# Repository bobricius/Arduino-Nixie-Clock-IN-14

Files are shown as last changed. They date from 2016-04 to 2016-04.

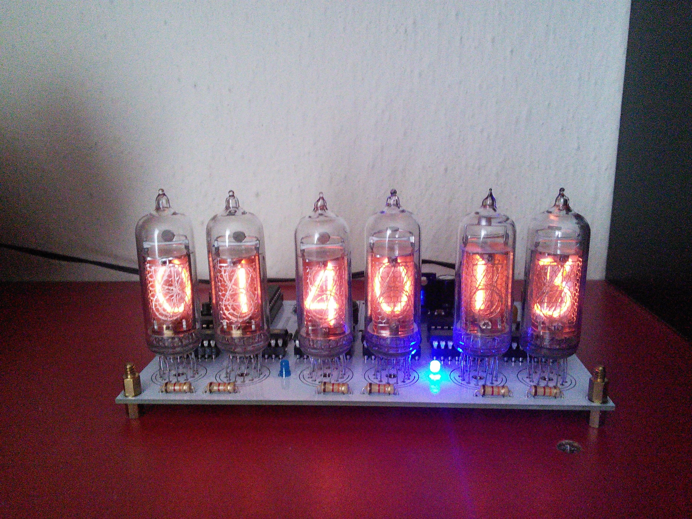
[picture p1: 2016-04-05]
Images/a2.jpg

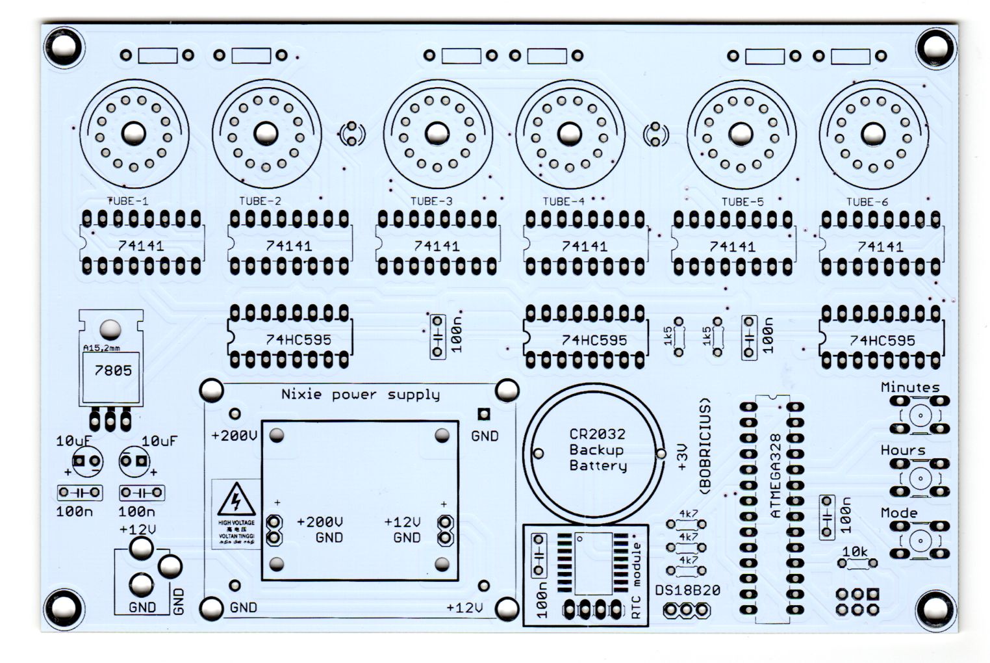
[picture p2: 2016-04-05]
Images/bare_t.jpg

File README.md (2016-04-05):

Features:

- 24h mode
- easy assembly
- arduino compatible firmware ATMEGA328 or another runing on internal RC oscillator (no crystal needed )
- ultra high precise time with RTC DS3231 onboard or RTC module
- CR2032 battery backup
- separated HV power supply (not included, you can connect any HV module) 
 etc. specially THIS ONE from ebay fit prefect.
- beautiful white single board 
- readable clean design
- cathode poisoning prevention
- 3mm holes under nixies for optional back-light
- optional DS18B20 sensor
- dimensions 15cm x 10cm

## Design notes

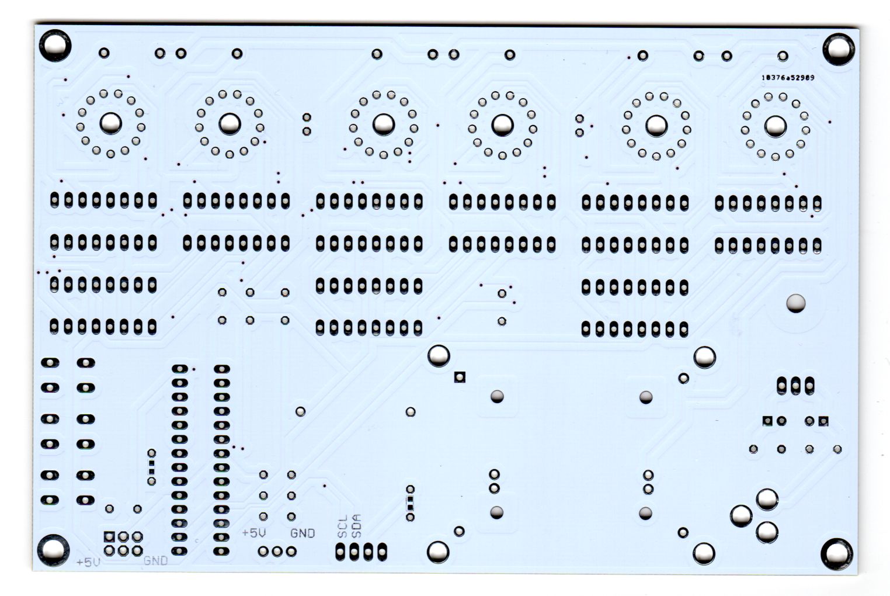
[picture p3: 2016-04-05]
Images/bare_b.jpg

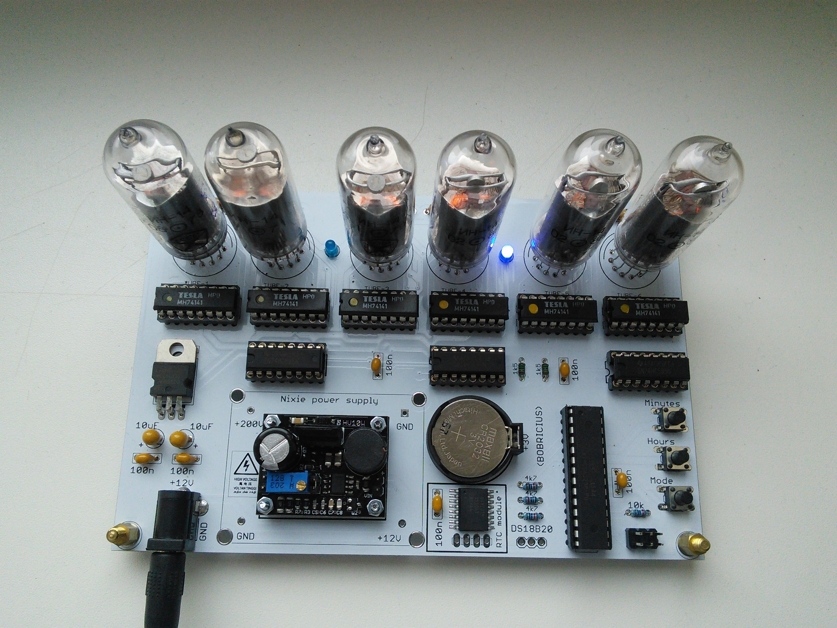
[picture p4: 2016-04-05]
Images/a1.jpg

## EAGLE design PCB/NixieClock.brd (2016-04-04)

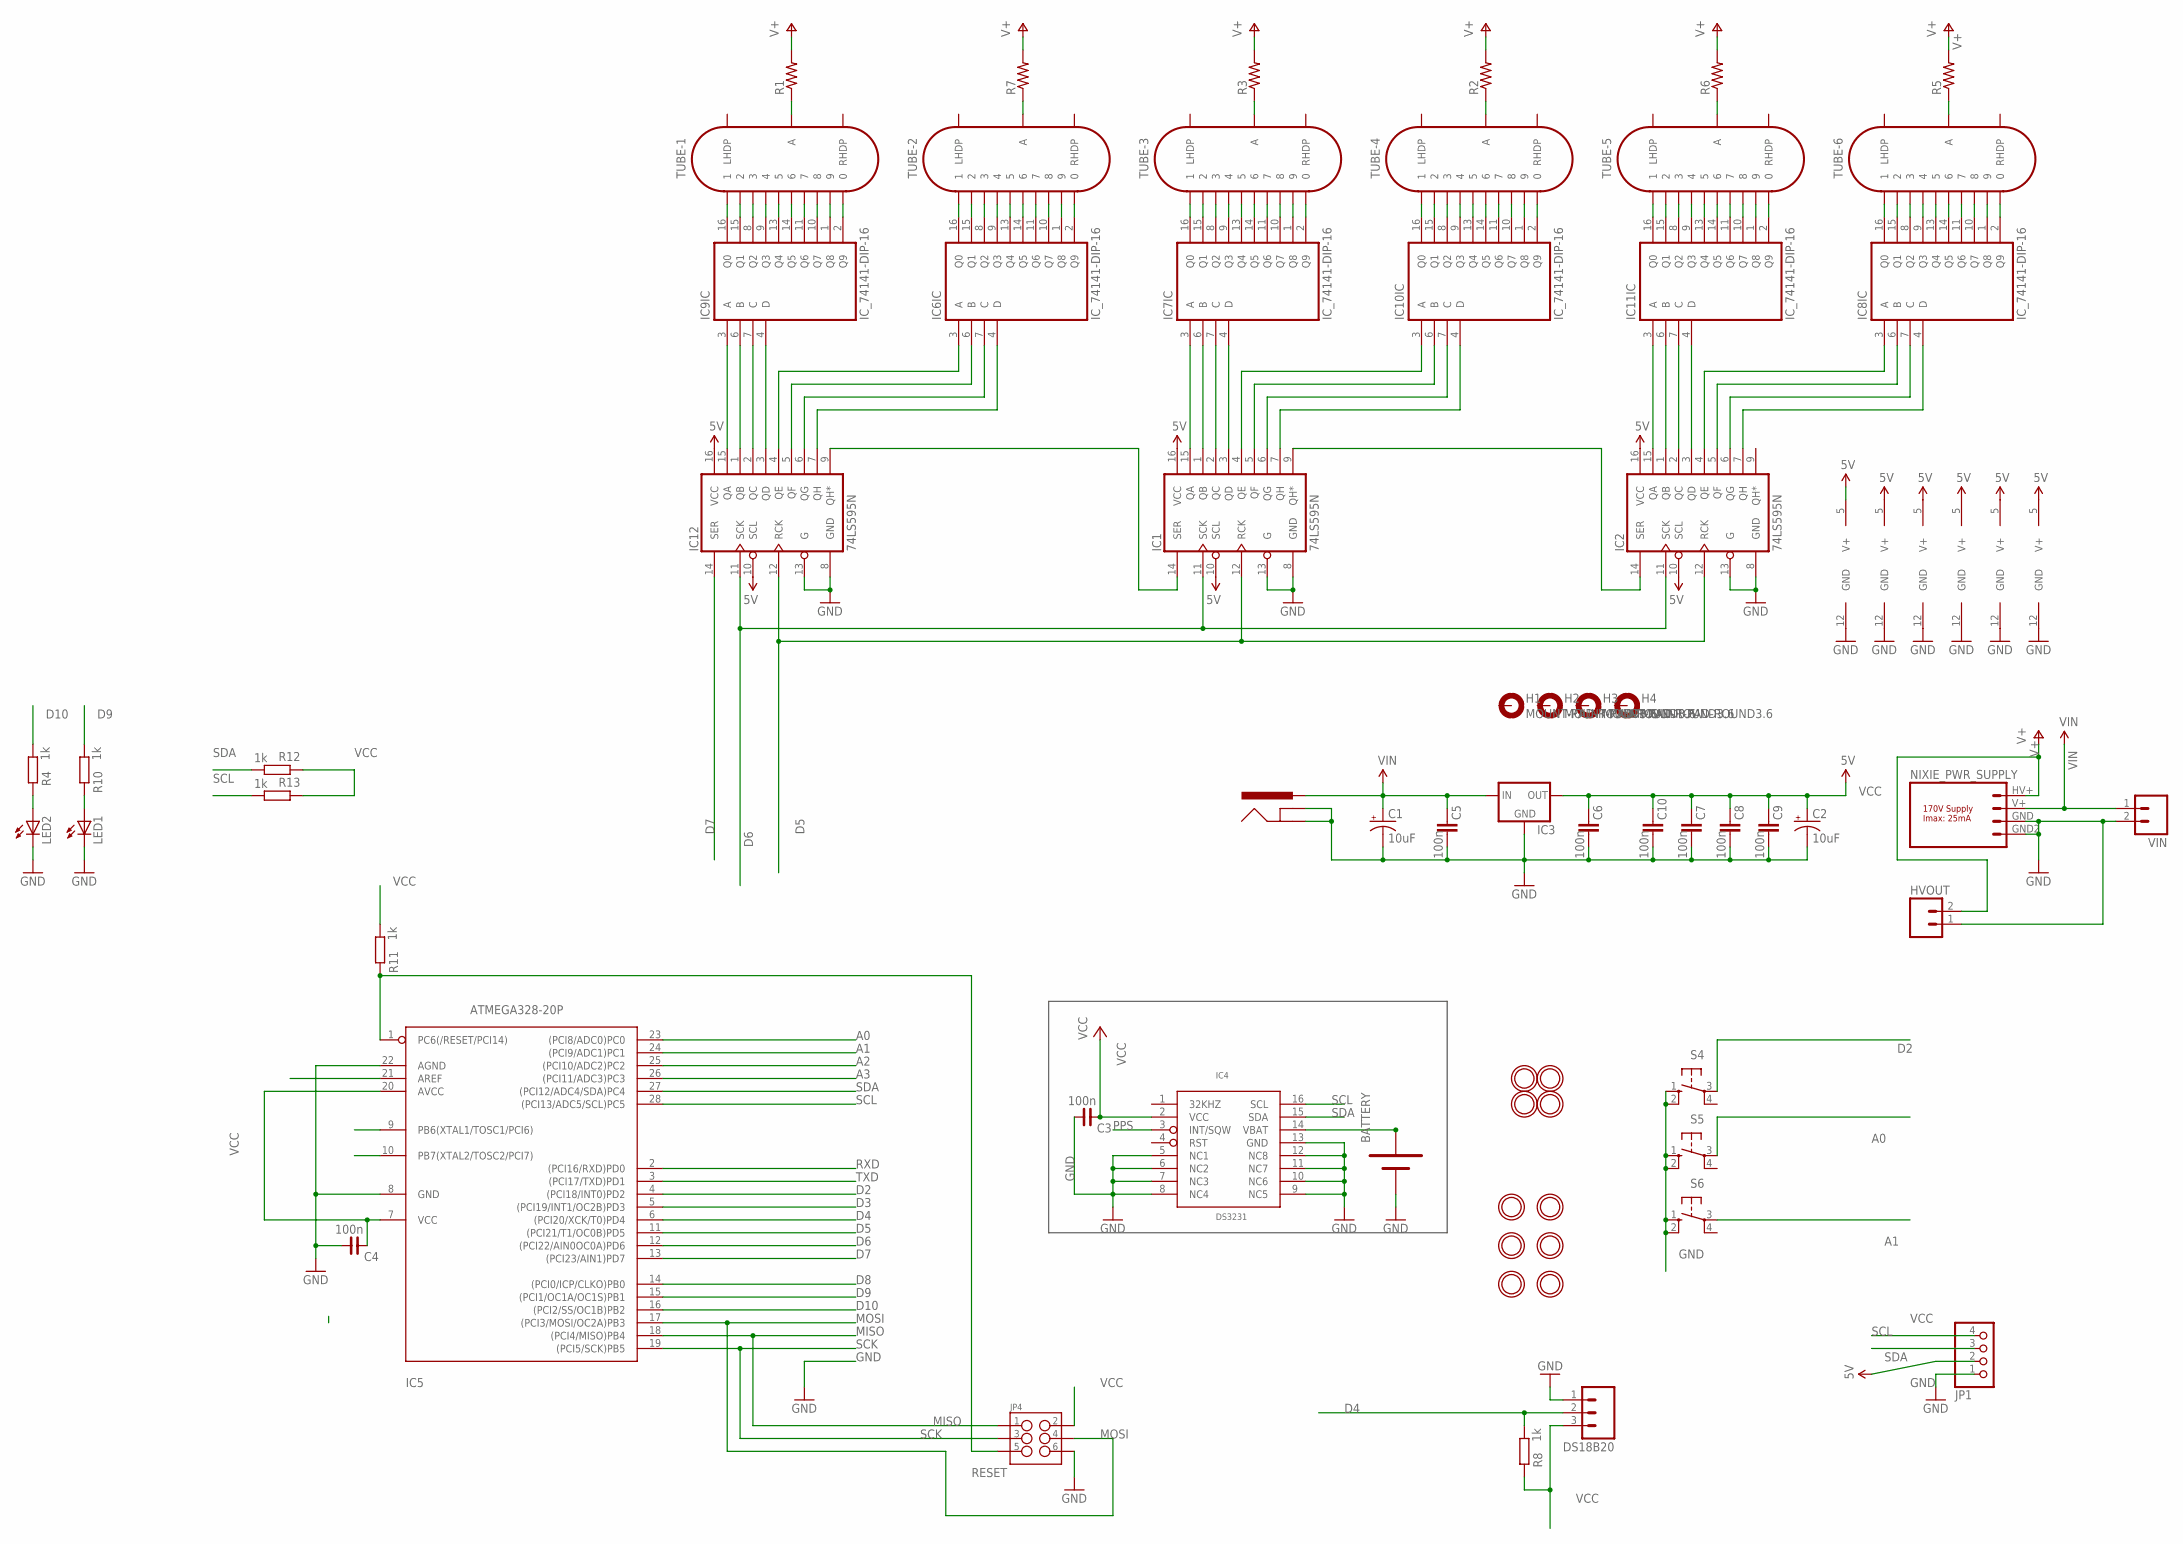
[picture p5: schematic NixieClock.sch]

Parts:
BATTERY: BATTERY-1XAA20MM; BATTCOM_20MM_PTH
C1, C2: 10uF; CPOL-RADIAL-10UF-25V
C3, C4: 100n; C0603
C5, C6, C7, C8, C9, C10: 100n; C050-025X075
DS18B20: DS18B20DS18B20; DS18B20
H1, H2, H3, H4: MOUNT-PAD-ROUND3.6; 3,6-PAD
HVOUT: M02PTH; 1X02
IC1, IC2, IC12: 74LS595N; DIL16
IC3: V_REG_78XXSIDE; 78XXL
IC4: DS3231; SO16W
IC5: ATMEGA328-20P; DIL28-3
IC6, IC7, IC8, IC9, IC10, IC11: IC_74141-DIP-16; DIL16
J1: POWER_JACKPTH; POWER_JACK_PTH
JP1: PINHD-1X4; 1X04
JP4: M03X2NO_SILK; 2X3-NS
LED1, LED2: LED3MM
NIXIE_PWR_SUPPLY: NIXIE_PWR_SUPPLYPTH; NIXIE_PWR_SUPPLY
R1, R2, R3, R5, R6, R7: RESISTORPTH-1/4W; AXIAL-0.4
R4, R8, R10, R11, R12, R13: 1k; 0204/5
S4, S5, S6: 10-XX; B3F-10XX
TUBE-1, TUBE-2, TUBE-3, TUBE-4, TUBE-5, TUBE-6: IN-14
U$10, U$11, U$16, U$17, U$18, U$19, U$21, U$22, U$23, U$24: MOUNTINGHOLE3.0THIN; MOUNTINGHOLE_3.0_PLATEDTHIN
VIN: M02PTH; 1X02

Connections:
A0: IC5.23 ((PCI8/ADC0)PC0), S5.3
A1: IC5.24 ((PCI9/ADC1)PC1), S6.3
A2: IC5.25 ((PCI10/ADC2)PC2)
A3: IC5.26 ((PCI11/ADC3)PC3)
AREF_RAW: IC5.21 (AREF)
D2: IC5.4 ((PCI18/INT0)PD2), S4.3
D3: IC5.5 ((PCI19/INT1/OC2B)PD3)
D4: DS18B20.2 (DS), IC5.6 ((PCI20/XCK/T0)PD4), R8.1
D5: IC1.12 (RCK), IC2.12 (RCK), IC5.11 ((PCI21/T1/OC0B)PD5), IC12.12 (RCK)
D6: IC1.11 (SCK), IC2.11 (SCK), IC5.12 ((PCI22/AIN0OC0A)PD6), IC12.11 (SCK)
D7: IC5.13 ((PCI23/AIN1)PD7), IC12.14 (SER)
D8: IC5.14 ((PCI0/ICP/CLKO)PB0)
D9: IC5.15 ((PCI1/OC1A/OC1S)PB1), R10.1
D10: IC5.16 ((PCI2/SS/OC1B)PB2), R4.1
GND: BATTERY.-, C1.2 (-), C2.2 (-), C3.1, C4.1, C5.2, C6.2, C7.2, C8.2, C9.2, C10.2, DS18B20.1 (GND), HVOUT.1, IC1.8 (GND), IC1.13 (G), IC2.8 (GND), IC2.13 (G), IC3.GND, IC4.5 (NC1), IC4.6 (NC2), IC4.7 (NC3), IC4.8 (NC4), IC4.9 (NC5), IC4.10 (NC6), IC4.11 (NC7), IC4.12 (NC8), IC4.13 (GND), IC5.8 (GND), IC5.22 (AGND), IC6.12 (GND), IC7.12 (GND), IC8.12 (GND), IC9.12 (GND), IC10.12 (GND), IC11.12 (GND), IC12.8 (GND), IC12.13 (G), J1.GND, J1.GNDBREAK, JP1.1, JP4.6, LED1.K (C), LED2.K (C), NIXIE_PWR_SUPPLY.GND (4), NIXIE_PWR_SUPPLY.GND2 (1), S4.1 (S), S4.2 (S1), S5.1 (S), S5.2 (S1), S6.1 (S), S6.2 (S1), VIN.2
MISO: IC5.18 ((PCI4/MISO)PB4), JP4.1
MOSI: IC5.17 ((PCI3/MOSI/OC2A)PB3), JP4.4
unnamed: R1.P$1 (1), TUBE-1.A
unnamed: R7.P$1 (1), TUBE-2.A
unnamed: R3.P$1 (1), TUBE-3.A
unnamed: R2.P$1 (1), TUBE-4.A
unnamed: R6.P$1 (1), TUBE-5.A
unnamed: R5.P$1 (1), TUBE-6.A
unnamed: IC9.16 (Q0), TUBE-1.1
unnamed: IC9.15 (Q1), TUBE-1.2
unnamed: IC9.8 (Q2), TUBE-1.3
unnamed: IC9.9 (Q3), TUBE-1.4
unnamed: IC9.13 (Q4), TUBE-1.5
unnamed: IC9.14 (Q5), TUBE-1.6
unnamed: IC9.11 (Q6), TUBE-1.7
unnamed: IC9.10 (Q7), TUBE-1.8
unnamed: IC9.1 (Q8), TUBE-1.9
unnamed: IC9.2 (Q9), TUBE-1.0
unnamed: IC6.16 (Q0), TUBE-2.1
unnamed: IC6.15 (Q1), TUBE-2.2
unnamed: IC6.8 (Q2), TUBE-2.3
unnamed: IC6.9 (Q3), TUBE-2.4
unnamed: IC6.13 (Q4), TUBE-2.5
unnamed: IC6.14 (Q5), TUBE-2.6
unnamed: IC6.11 (Q6), TUBE-2.7
unnamed: IC6.10 (Q7), TUBE-2.8
unnamed: IC6.1 (Q8), TUBE-2.9
unnamed: IC6.2 (Q9), TUBE-2.0
unnamed: IC7.16 (Q0), TUBE-3.1
unnamed: IC7.15 (Q1), TUBE-3.2
unnamed: IC7.8 (Q2), TUBE-3.3
unnamed: IC7.9 (Q3), TUBE-3.4
unnamed: IC7.13 (Q4), TUBE-3.5
unnamed: IC7.14 (Q5), TUBE-3.6
unnamed: IC7.11 (Q6), TUBE-3.7
unnamed: IC7.10 (Q7), TUBE-3.8
unnamed: IC7.1 (Q8), TUBE-3.9
unnamed: IC7.2 (Q9), TUBE-3.0
unnamed: IC10.16 (Q0), TUBE-4.1
unnamed: IC10.15 (Q1), TUBE-4.2
unnamed: IC10.8 (Q2), TUBE-4.3
unnamed: IC10.9 (Q3), TUBE-4.4
unnamed: IC10.13 (Q4), TUBE-4.5
unnamed: IC10.14 (Q5), TUBE-4.6
unnamed: IC10.11 (Q6), TUBE-4.7
unnamed: IC10.10 (Q7), TUBE-4.8
unnamed: IC10.1 (Q8), TUBE-4.9
unnamed: IC10.2 (Q9), TUBE-4.0
unnamed: IC11.16 (Q0), TUBE-5.1
unnamed: IC11.15 (Q1), TUBE-5.2
unnamed: IC11.8 (Q2), TUBE-5.3
unnamed: IC11.9 (Q3), TUBE-5.4
unnamed: IC11.13 (Q4), TUBE-5.5
unnamed: IC11.14 (Q5), TUBE-5.6
unnamed: IC11.11 (Q6), TUBE-5.7
unnamed: IC11.10 (Q7), TUBE-5.8
unnamed: IC11.1 (Q8), TUBE-5.9
unnamed: IC11.2 (Q9), TUBE-5.0
unnamed: IC8.16 (Q0), TUBE-6.1
unnamed: IC8.15 (Q1), TUBE-6.2
unnamed: IC8.8 (Q2), TUBE-6.3
unnamed: IC8.9 (Q3), TUBE-6.4
unnamed: IC8.13 (Q4), TUBE-6.5
unnamed: IC8.14 (Q5), TUBE-6.6
unnamed: IC8.11 (Q6), TUBE-6.7
unnamed: IC8.10 (Q7), TUBE-6.8
unnamed: IC8.1 (Q8), TUBE-6.9
unnamed: IC8.2 (Q9), TUBE-6.0
unnamed: IC1.1 (QB), IC7.6 (B)
unnamed: IC1.2 (QC), IC7.7 (C)
unnamed: IC1.3 (QD), IC7.4 (D)
unnamed: IC1.15 (QA), IC7.3 (A)
unnamed: IC9.6 (B), IC12.1 (QB)
unnamed: IC9.7 (C), IC12.2 (QC)
unnamed: IC9.4 (D), IC12.3 (QD)
unnamed: IC9.3 (A), IC12.15 (QA)
unnamed: IC2.1 (QB), IC11.6 (B)
unnamed: IC2.2 (QC), IC11.7 (C)
unnamed: IC2.3 (QD), IC11.4 (D)
unnamed: IC2.15 (QA), IC11.3 (A)
unnamed: IC6.3 (A), IC12.4 (QE)
unnamed: IC6.6 (B), IC12.5 (QF)
unnamed: IC6.7 (C), IC12.6 (QG)
unnamed: IC6.4 (D), IC12.7 (QH)
unnamed: IC1.14 (SER), IC12.9 (QH*)
unnamed: IC1.9 (QH*), IC2.14 (SER)
unnamed: IC1.4 (QE), IC10.3 (A)
unnamed: IC1.5 (QF), IC10.6 (B)
unnamed: IC1.6 (QG), IC10.7 (C)
unnamed: IC1.7 (QH), IC10.4 (D)
unnamed: LED2.A, R4.2
unnamed: IC2.4 (QE), IC8.3 (A)
unnamed: IC2.5 (QF), IC8.6 (B)
unnamed: IC2.6 (QG), IC8.7 (C)
unnamed: IC2.7 (QH), IC8.4 (D)
unnamed: BATTERY.+, IC4.14 (VBAT)
unnamed: LED1.A, R10.2
PPS: IC4.3 (INT/SQW)
RESET: IC5.1 (PC6(/RESET/PCI14)), JP4.5, R11.2
RXD: IC5.2 ((PCI16/RXD)PD0)
SCK: IC5.19 ((PCI5/SCK)PB5), JP4.3
SCL: IC4.16 (SCL), IC5.28 ((PCI13/ADC5/SCL)PC5), JP1.4, R13.1
SDA: IC4.15 (SDA), IC5.27 ((PCI12/ADC4/SDA)PC4), JP1.3, R12.1
TXD: IC5.3 ((PCI17/TXD)PD1)
V+: HVOUT.2, NIXIE_PWR_SUPPLY.HV+ (3), R1.P$2 (2), R2.P$2 (2), R3.P$2 (2), R5.P$2 (2), R6.P$2 (2), R7.P$2 (2)
VCC: C2.1 (+), C3.2, C4.2, C6.1, C7.1, C8.1, C9.1, C10.1, DS18B20.3 (5V), IC1.10 (SCL), IC1.16 (VCC), IC2.10 (SCL), IC2.16 (VCC), IC3.OUT, IC4.2 (VCC), IC5.7 (VCC), IC5.20 (AVCC), IC6.5 (V+), IC7.5 (V+), IC8.5 (V+), IC9.5 (V+), IC10.5 (V+), IC11.5 (V+), IC12.10 (SCL), IC12.16 (VCC), JP1.2, JP4.2, R8.2, R11.1, R12.2, R13.2
VIN: C1.1 (+), C5.1, IC3.IN, J1.PWR, NIXIE_PWR_SUPPLY.V+ (2), VIN.1

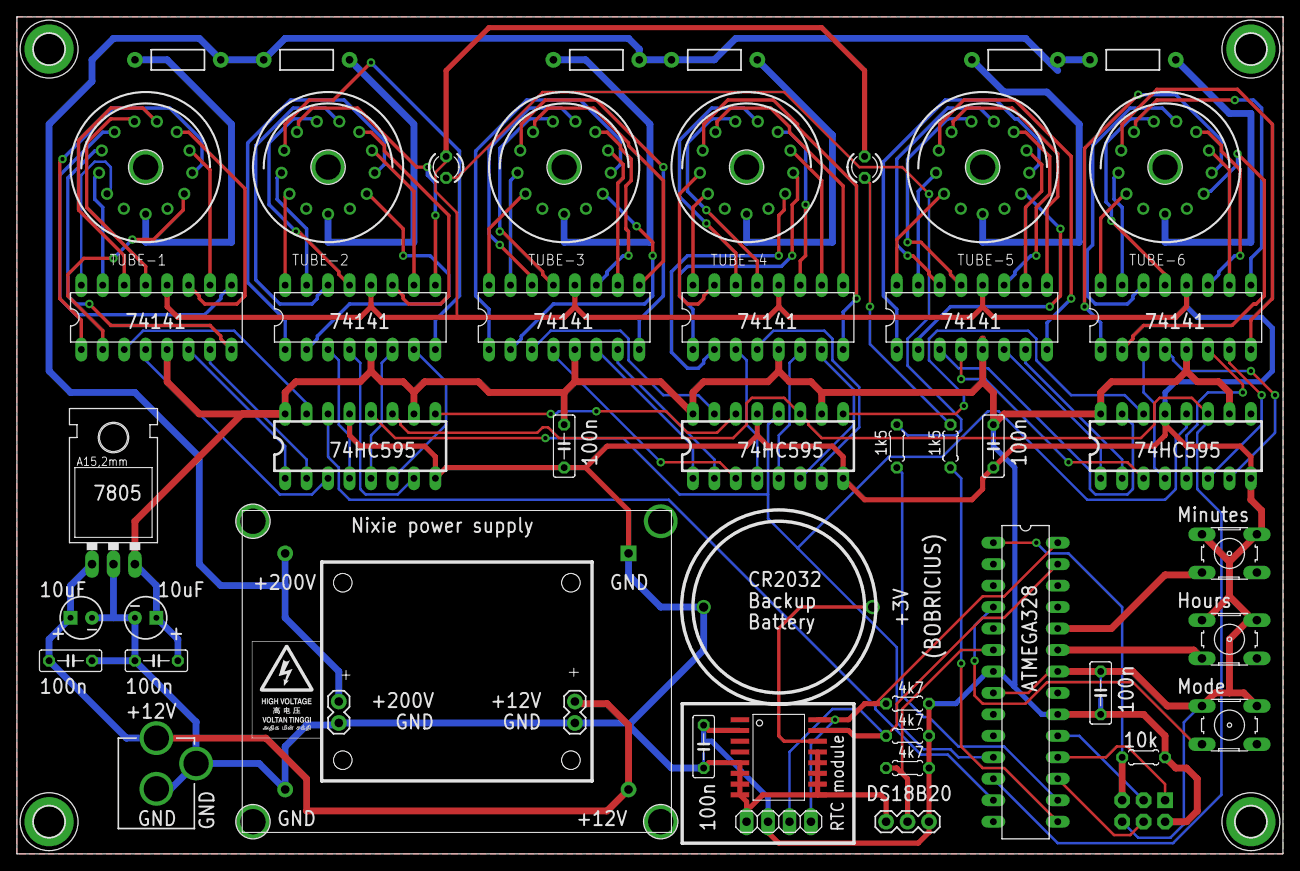
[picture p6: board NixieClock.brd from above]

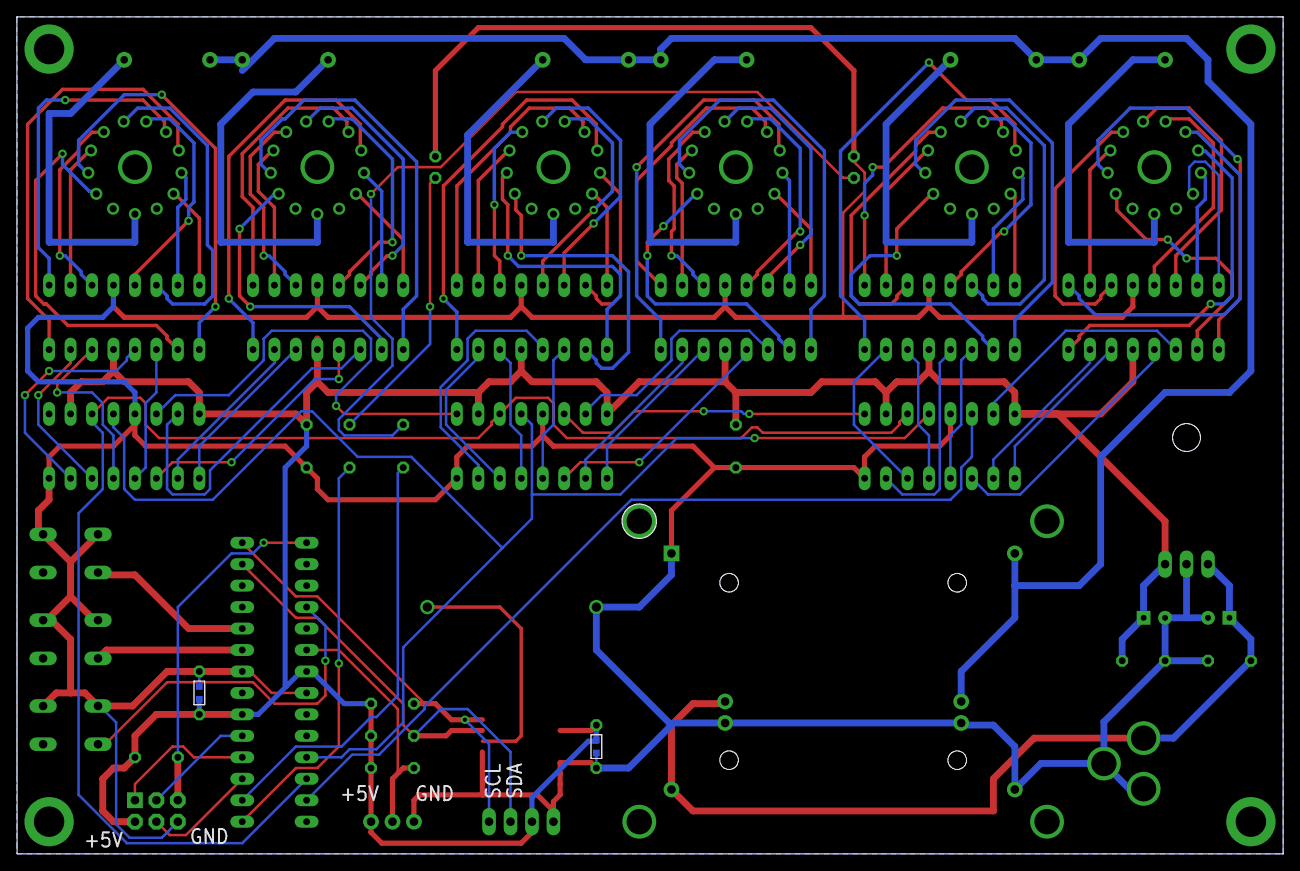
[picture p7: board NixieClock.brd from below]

Board: 2 copper layers, 149.9 x 99.1 mm, 68 parts (3 on the bottom side), 114 nets.

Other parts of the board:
U$20: HV03

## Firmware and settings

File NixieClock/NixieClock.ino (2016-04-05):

#include <Wire.h>
#include "RTClib.h"
#include "OneWire.h"

#include "Nixies.h"
#include "Registers.h"


OneWire ds(4); // Temperature Sensor on pin 2
RTC_DS1307 RTC;

const int led1 =  9;      // the number of the LED pin
const int led2 =  10;      // the number of the LED pin

#define modeBtn   2
#define hoursBtn   14
#define minutesBtn   15

unsigned int serialPin = 7 ;
unsigned int serialClockPin = 6;
unsigned int registerClockPin = 5;
int hour, minute, second; 

Nixies nixies;

void setup() {
//	Serial.begin(9600);
	Wire.begin();
	
	RTC.begin();
	if (!RTC.isrunning()) {
//		Serial.println("RTC needs to be set");
		RTC.adjust(DateTime(__DATE__, __TIME__));
	}

 pinMode(led1, OUTPUT);
 pinMode(led2, OUTPUT);   
   
 pinMode(modeBtn, INPUT);
 pinMode(hoursBtn, INPUT);    
 pinMode(minutesBtn, INPUT);

 digitalWrite(modeBtn, HIGH);
 digitalWrite(hoursBtn, HIGH);    
 digitalWrite(minutesBtn, HIGH);
 

	nixies.initialize(serialPin, serialClockPin, registerClockPin, 6);
}

//		RTC.adjust(DateTime(atoi(array[1])/*Year*/, atoi(array[2])/*Month*/, atoi(array[3])/*Day*/, atoi(array[4])/*Hour*/, atoi(array[5])/*Minute*/, atoi(array[6])/*Second*/));
    // following line sets the RTC to the date & time this sketch was compiled
//    rtc.adjust(DateTime(F(__DATE__), F(__TIME__)));
    // This line sets the RTC with an explicit date & time, for example to set
    // January 21, 2014 at 3am you would call:
    // rtc.adjust(DateTime(2014, 1, 21, 3, 0, 0));





void displayTime() {

	nixies.setNixie(5, hour/10);
	nixies.setNixie(4, hour%10);
	nixies.setNixie(3, minute/10);
	nixies.setNixie(2, minute%10);
	nixies.setNixie(1, second/10);
	nixies.setNixie(0, second%10);
	nixies.update();
}

void loop() {
	  DateTime now = RTC.now();
   hour = now.hour();
   minute = now.minute();
   second = now.second();

if (second==0)
{
  testTubes();
}
  
  if (digitalRead(hoursBtn)==LOW)
  {
    hour++;
    if (hour > 23) {
      hour = 0;
    }
    if (hour < 0) {
      hour = 23;
    }
  
    digitalWrite(led2, HIGH);
    delay(110);
    digitalWrite(led2, LOW);
    delay(110); 
     second=1; 
    RTC.adjust(DateTime(2014, 1, 21, hour, minute, second));
  }

  if (digitalRead(minutesBtn)==LOW)
  {
     minute++;
    if (minute > 59) {
      minute = 0;
    }
    if (minute < 0) {
      minute = 59;
    }

    digitalWrite(led2, HIGH);
    delay(110);
    digitalWrite(led2, LOW);
    delay(110); 
     second=1; 
    RTC.adjust(DateTime(2014, 1, 21, hour, minute, second));
  }

    if (digitalRead(modeBtn)==LOW)
  {

    displayTemperature();
//    testTubes();
  }

//    digitalWrite(led1, HIGH);
//    delay(100);
//    digitalWrite(led1, LOW);
//    delay(100);


//
//
//  // fade in from min to max in increments of 5 points:
//  for (int fadeValue = 0 ; fadeValue <= 255; fadeValue += 5) {
//    // sets the value (range from 0 to 255):
//    analogWrite(led2, fadeValue);
//    // wait for 30 milliseconds to see the dimming effect
//    delay(1);
//  }
//
//  // fade out from max to min in increments of 5 points:
//  for (int fadeValue = 255 ; fadeValue >= 0; fadeValue -= 5) {
//    // sets the value (range from 0 to 255):
//    analogWrite(led2, fadeValue);
//    // wait for 30 milliseconds to see the dimming effect
//    delay(1);
//  }
  
  displayTime();
}

// Code for this function from http://bildr.org/2011/07/ds18b20-arduino/
// Copyright (c) 2010 bildr community

float getTemperature() {
	//returns the temperature from one DS18S20 in DEG Celsius
	byte data[12];
	byte addr[8];
	
	if (!ds.search(addr)) {
		//no more sensors on chain, reset search
		ds.reset_search();
		return -1000;
	}
	
	if (OneWire::crc8(addr, 7)!=addr[7]) {
//		Serial.println("CRC is not valid!");
		return -1000;
	}

	if (addr[0]!=0x10 && addr[0]!=0x28) {
//		Serial.print("Device is not recognized");
		return -1000;
	}

	ds.reset();
	ds.select(addr);
	ds.write(0x44,1); // start conversion, with parasite power on at the end

	byte present = ds.reset();
	ds.select(addr);
	ds.write(0xBE); // Read Scratchpad


	for (int i=0; i<9; i++) { // we need 9 bytes
		data[i] = ds.read();
	}

	ds.reset_search();

	byte MSB = data[1];
	byte LSB = data[0];

	float tempRead = ((MSB << 8) | LSB); //using two's compliment
	float TemperatureSum = tempRead / 16;

	return TemperatureSum;
}


void displayTemperature() {
  int temperature = getTemperature();
  
  nixies.setNixie(5, temperature/10);
  nixies.setNixie(4, temperature%10);
  nixies.setNixie(3, 10);
  nixies.setNixie(2, 10);
  nixies.setNixie(1, 10);
  nixies.setNixie(0, 10);
  nixies.update();
  // fade in from min to max in increments of 5 points:
  for (int fadeValue = 0 ; fadeValue <= 255; fadeValue += 5) {
    // sets the value (range from 0 to 255):
    analogWrite(led1, fadeValue);
    // wait for 30 milliseconds to see the dimming effect
    delay(30);
  }

  // fade out from max to min in increments of 5 points:
  for (int fadeValue = 255 ; fadeValue >= 0; fadeValue -= 5) {
    // sets the value (range from 0 to 255):
    analogWrite(led1, fadeValue);
    // wait for 30 milliseconds to see the dimming effect
    delay(30);
  }
}

void testTubes() {
  // Test every digit
  for (int i=0; i<10; i++) {
   DateTime now = RTC.now();
   second = now.second();
    
  nixies.setNixie(5, i);
  nixies.setNixie(4, i);
  nixies.setNixie(3, i);
  nixies.setNixie(2, i);
  nixies.setNixie(1, second/10);
  nixies.setNixie(0, second%10);
    nixies.update();
    digitalWrite(led2, HIGH);
    delay(1);
    digitalWrite(led2, LOW);
    delay(200);
  }

//  // Test setting to blank
//  nixies.setNixie(0, 10);
//  nixies.setNixie(1, 10);
//  nixies.setNixie(2, 10);
//  nixies.setNixie(3, 10);
//  nixies.setNixie(4, 10);
//  nixies.setNixie(5, 10);
//  nixies.update();
//
//    digitalWrite(led1, HIGH);
//    delay(300);
//    digitalWrite(led1, LOW);
}

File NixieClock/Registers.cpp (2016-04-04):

//
//  Registers.cpp
//
//  Created by Mr. Gecko's Media (James Coleman) on 7/23/14.
//  No Copyright Claimed. Public Domain.
//

#include "Registers.h"

#if (ARDUINO >= 100)
#include "Arduino.h"
#else
#include "WProgram.h"
#endif

Registers::Registers() {
	serialPin = 0;
	serialClockPin = 0;
	registerClockPin = 0;
	
	registerCount = 0;
}

bool Registers::initialize(unsigned int theSerialPin, unsigned int theSerialClockPin, unsigned int theRegisterClockPin, unsigned int theRegisterCount) {
	if (theRegisterCount>25)
		return false;
	
	serialPin = theSerialPin;
	serialClockPin = theSerialClockPin;
	registerClockPin = theRegisterClockPin;
	
	pinMode(serialPin, OUTPUT);
	pinMode(serialClockPin, OUTPUT);
	pinMode(registerClockPin, OUTPUT);
	
	registerCount = theRegisterCount;
	
	setAllPins(LOW);
	return true;
}

bool Registers::setPin(unsigned int pin, bool value) {
	unsigned int registerNumber = pin/8;
	unsigned int pinNumber = pin%8;
	if (registerNumber>=registerCount)
		return false;
	
	byte registerValue = registerValues[registerNumber];
	registerValue &= ~(1 << pinNumber); // Sets pin to LOW
	registerValue |= (value << pinNumber); // Sets pin to value
	registerValues[registerNumber] = registerValue;
	return true;
}

void Registers::setAllPins(bool value) {
	if (registerCount==0)
		return;
	for (int i=0; i<(registerCount*8); i++) {
		setPin(i, value);
	}
}

void Registers::update() {
	if (registerCount==0)
		return;
	// Prepare for updating
	digitalWrite(registerClockPin, LOW);
	digitalWrite(serialPin, LOW);
	digitalWrite(serialClockPin, LOW);
	
	for (int registerNumber = registerCount-1; registerNumber>=0; registerNumber--) {
		byte registerValue = registerValues[registerNumber];
		for (int pinNumber = 7; pinNumber>=0; pinNumber--) {
			digitalWrite(serialClockPin, LOW); // Tell register that a value is getting ready to be written
			
			bool value = registerValue & (1 << pinNumber); // Grab value for pin
			digitalWrite(serialPin, value); // Write value
			
			digitalWrite(serialClockPin, HIGH); // Tell register to capture new value
		}
	}
	
	digitalWrite(serialClockPin, LOW); // Close out register
	digitalWrite(registerClockPin, HIGH); // Make new values live
}

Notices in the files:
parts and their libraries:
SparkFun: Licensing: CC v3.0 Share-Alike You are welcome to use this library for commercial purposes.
